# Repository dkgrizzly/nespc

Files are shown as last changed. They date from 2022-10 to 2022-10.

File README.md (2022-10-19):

# NES as an 8-Bit PC

This is very much a work in progress, and should be treated as such.

Based on the work done by [Joseph Marlin](https://github.com/jmarlin/) on his YouTube channel [TrackZero](https://www.youtube.com/c/TrackZeroFutzin).
Attaching a standard floppy disk controller (FDC) to a NES-001 game console with BASIC and Monitor in ROM.

I've separated the FDC to a mezzanine card which can be extended outside the case on a 40-pin IDC cable.
Partly due to the relative scarcity of the chips, and partly due to the complexity of the signal routing involved.
The FDC and additonal expansion cards share an 8-bit data and 8-bit address bus. The bus has eight select lines in addition to the FDC selects.

Expansion cards should be connected with 40-pin IDC edge connectors. The expansion bus cable should have three twists as show in expansion.txt.

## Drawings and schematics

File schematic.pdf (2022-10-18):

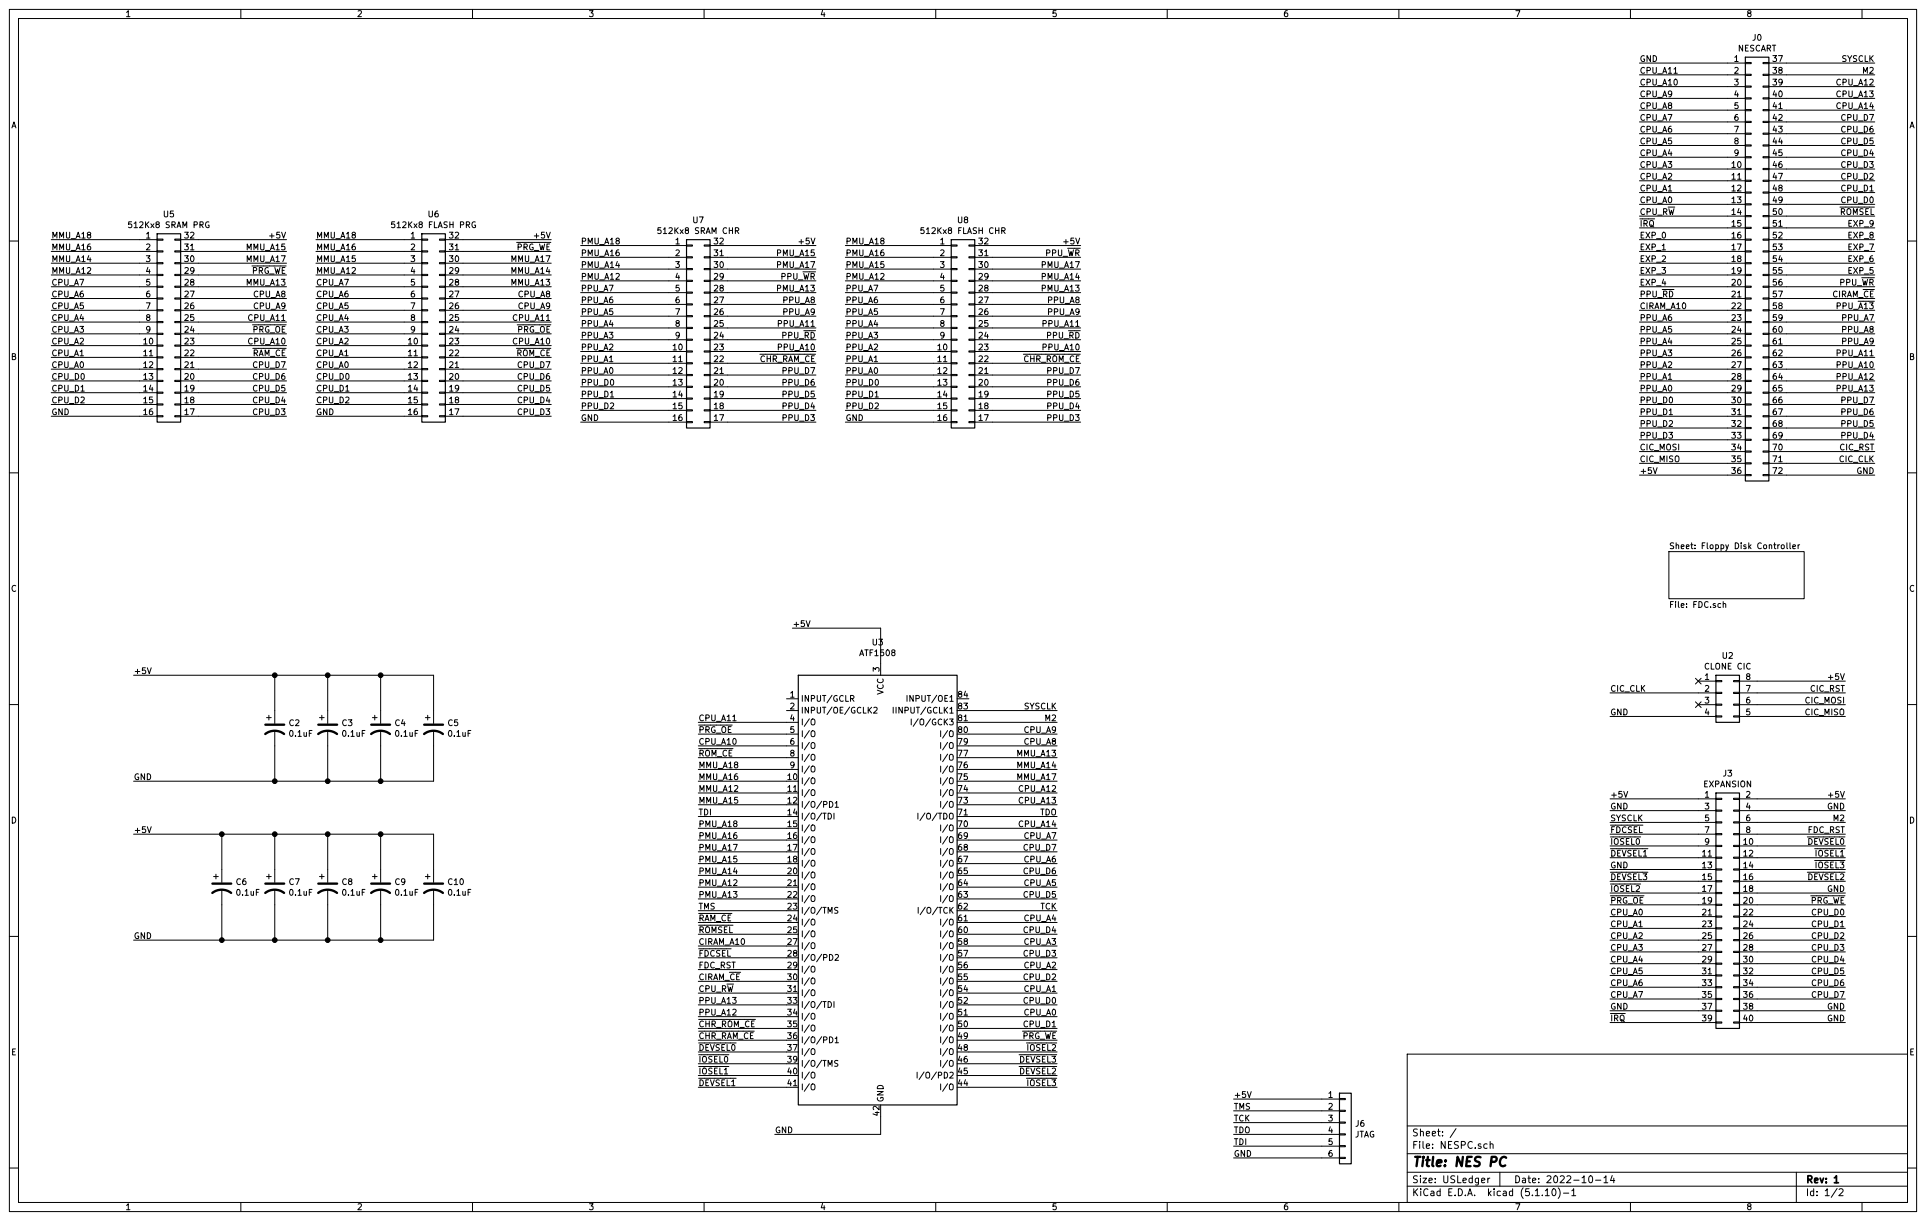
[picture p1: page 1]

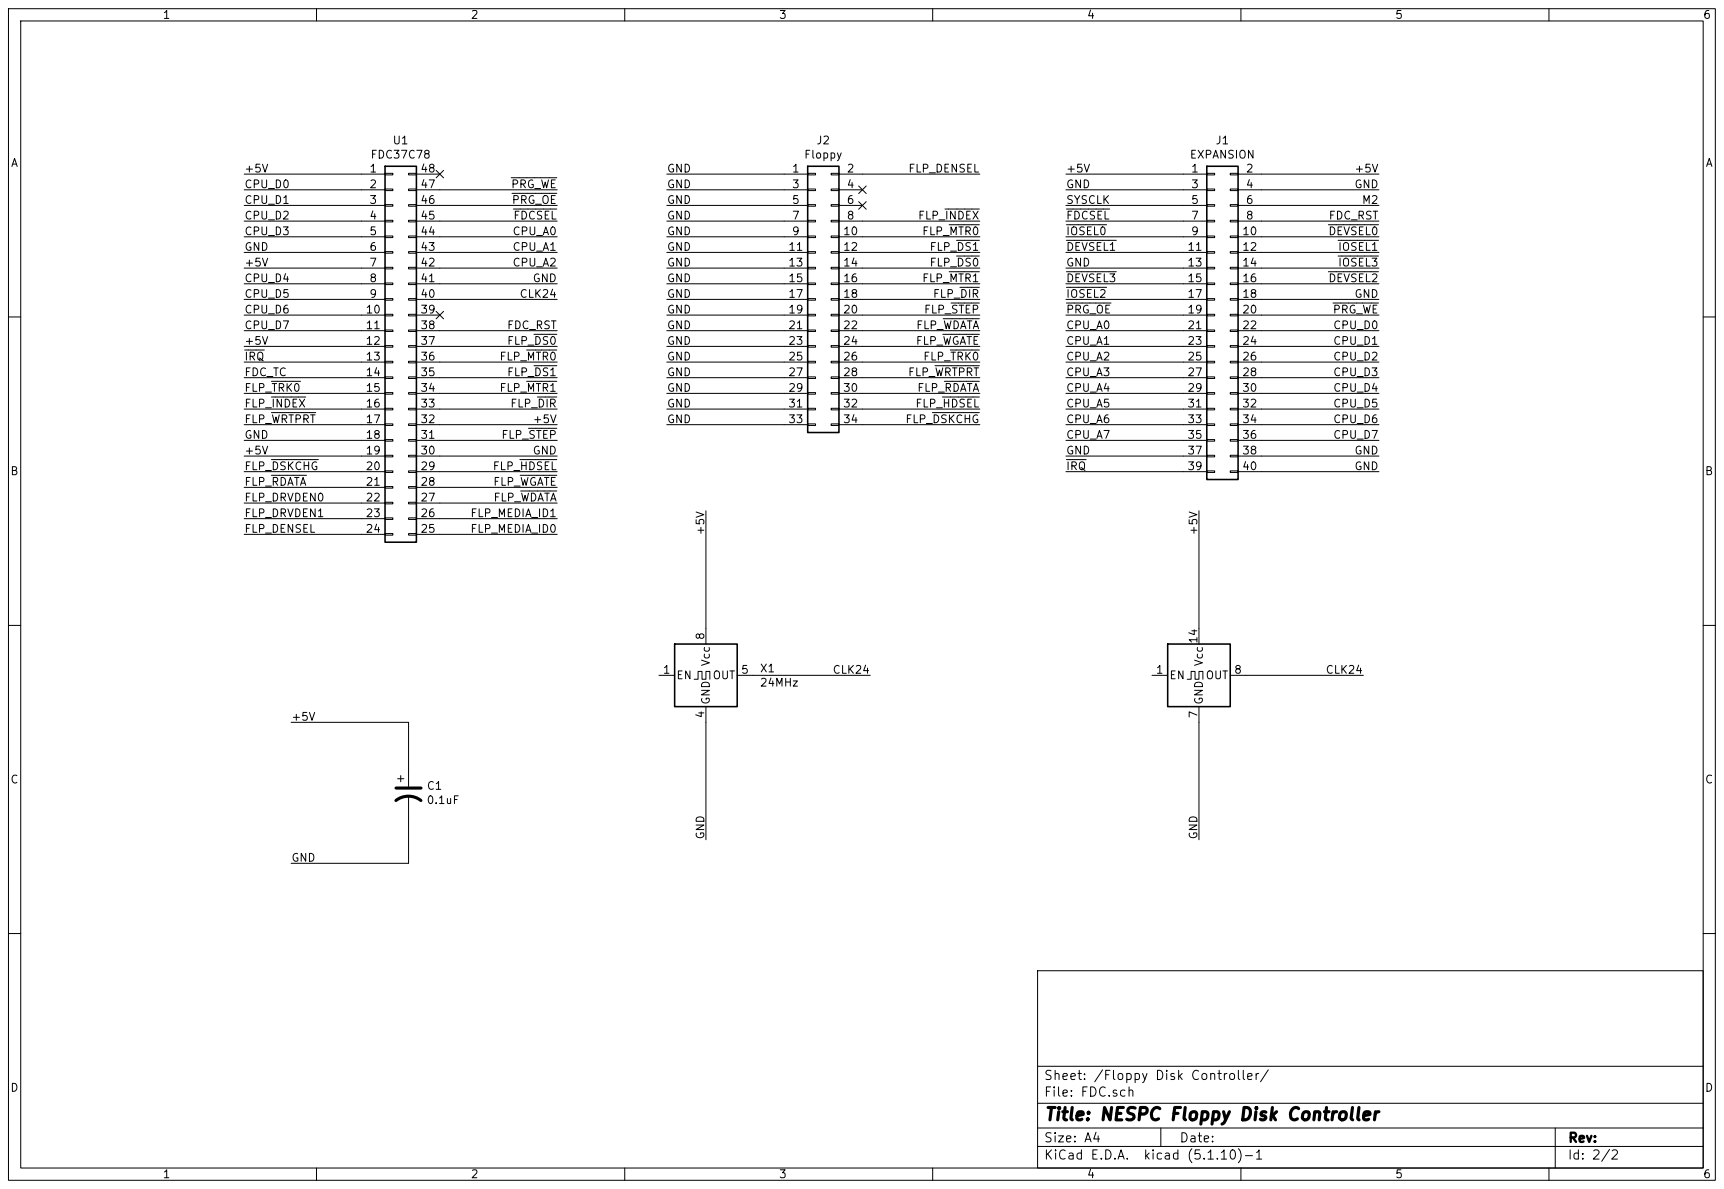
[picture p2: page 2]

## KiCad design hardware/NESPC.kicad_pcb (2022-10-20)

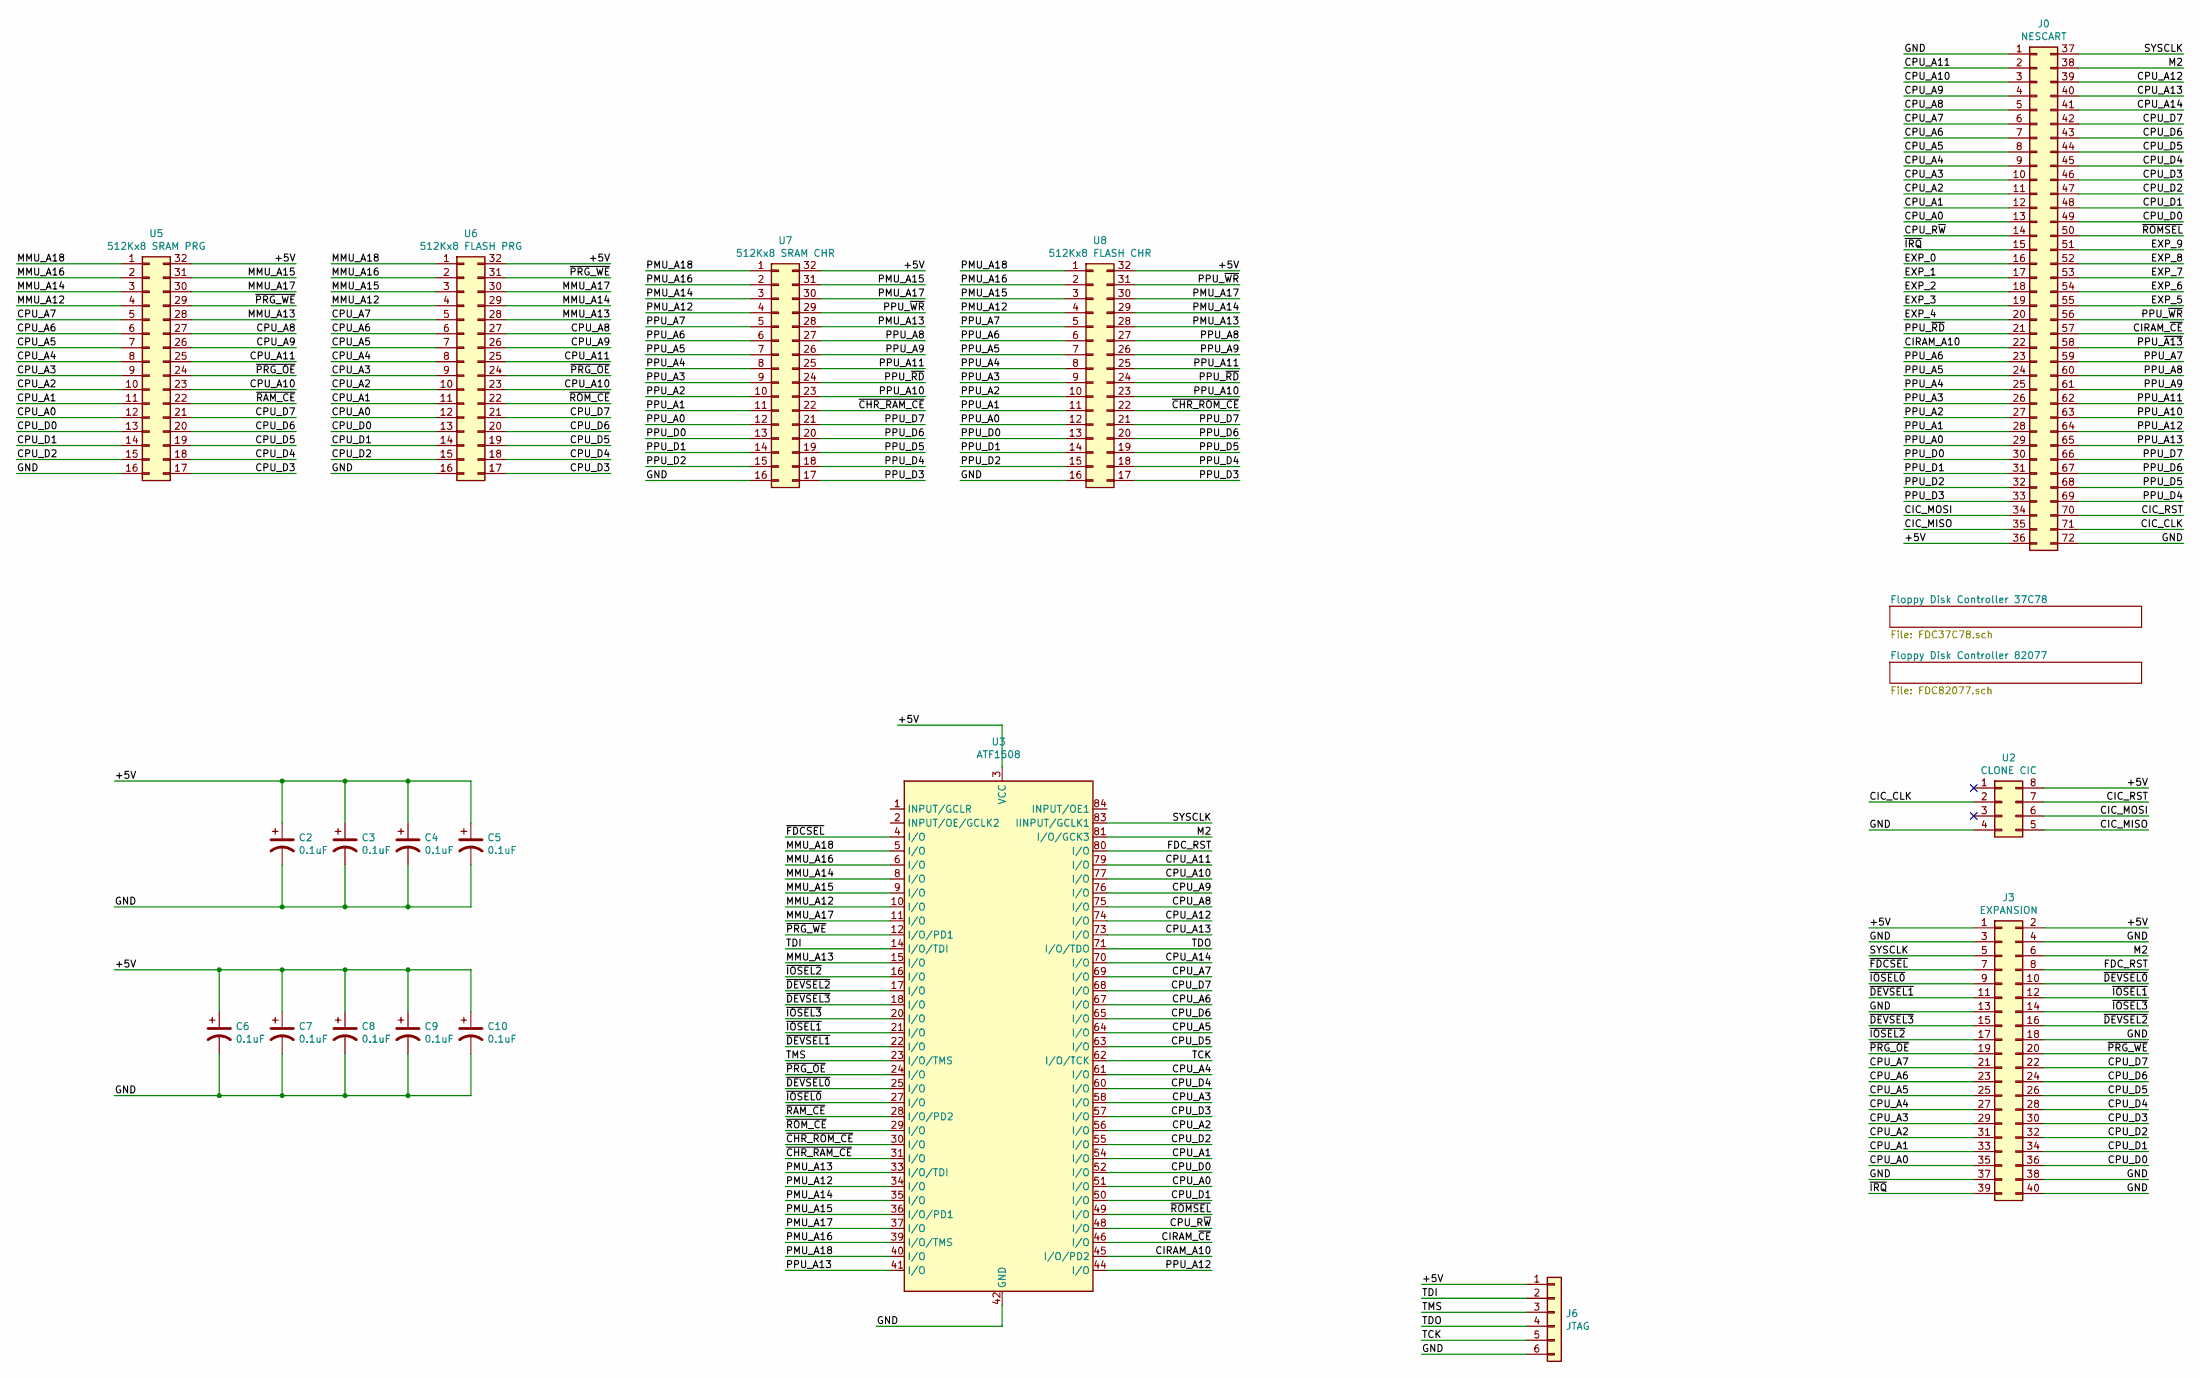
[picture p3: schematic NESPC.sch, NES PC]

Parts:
C2, C3, C4, C5, C6, C7, C8, C9, C10: 0.1uF; C_0603_1608Metric_Pad1.08x0.95mm_HandSolder
J0: NESCART; NES_CART
J3: EXPANSION; PinHeader_2x20_P2.54mm_Vertical
J6: JTAG; PinHeader_1x06_P2.54mm_Vertical
U2: CLONE CIC; DIP-8_W7.62mm
U3: ATF1508; PLCC-84
U5: 512Kx8 SRAM PRG; DIP-32_W15.24mm
U6: 512Kx8 FLASH PRG; DIP-32_W15.24mm
U7: 512Kx8 SRAM CHR; DIP-32_W15.24mm
U8: 512Kx8 FLASH CHR; DIP-32_W15.24mm

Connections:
/+5V: C2.1, C3.1, C4.1, C5.1, C6.1, C7.1, C8.1, C9.1, C10.1, J0.36, J3.1, J3.2, J6.1, U2.8, U3.3 (VCC), U3.13 (VCC), U3.26 (VCC), U3.38 (VCC), U3.43 (VCC), U3.53 (VCC), U3.66 (VCC), U3.78 (VCC), U5.32, U6.32, U7.32, U8.32
/CIC_CLK: J0.71, U2.2
/CIC_MISO: J0.35, U2.5
/CIC_MOSI: J0.34, U2.6
/CIC_RST: J0.70, U2.7
/CIRAM_A10: J0.22, U3.45 (I/O/PD2)
/CIRAM_~CE: J0.57, U3.46 (I/O)
/CPU_A0: J0.13, J3.35, U3.51 (I/O), U5.12, U6.12
/CPU_A1: J0.12, J3.33, U3.54 (I/O), U5.11, U6.11
/CPU_A2: J0.11, J3.31, U3.56 (I/O), U5.10, U6.10
/CPU_A3: J0.10, J3.29, U3.58 (I/O), U5.9, U6.9
/CPU_A4: J0.9, J3.27, U3.61 (I/O), U5.8, U6.8
/CPU_A5: J0.8, J3.25, U3.64 (I/O), U5.7, U6.7
/CPU_A6: J0.7, J3.23, U3.67 (I/O), U5.6, U6.6
/CPU_A7: J0.6, J3.21, U3.69 (I/O), U5.5, U6.5
/CPU_A8: J0.5, U3.75 (I/O), U5.27, U6.27
/CPU_A9: J0.4, U3.76 (I/O), U5.26, U6.26
/CPU_A10: J0.3, U3.77 (I/O), U5.23, U6.23
/CPU_A11: J0.2, U3.79 (I/O), U5.25, U6.25
/CPU_A12: J0.39, U3.74 (I/O)
/CPU_A13: J0.40, U3.73 (I/O)
/CPU_A14: J0.41, U3.70 (I/O)
/CPU_D0: J0.49, J3.36, U3.52 (I/O), U5.13, U6.13
/CPU_D1: J0.48, J3.34, U3.50 (I/O), U5.14, U6.14
/CPU_D2: J0.47, J3.32, U3.55 (I/O), U5.15, U6.15
/CPU_D3: J0.46, J3.30, U3.57 (I/O), U5.17, U6.17
/CPU_D4: J0.45, J3.28, U3.60 (I/O), U5.18, U6.18
/CPU_D5: J0.44, J3.26, U3.63 (I/O), U5.19, U6.19
/CPU_D6: J0.43, J3.24, U3.65 (I/O), U5.20, U6.20
/CPU_D7: J0.42, J3.22, U3.68 (I/O), U5.21, U6.21
/CPU_R~W: J0.14, U3.48 (I/O)
/EXP_0: J0.16
/EXP_1: J0.17
/EXP_2: J0.18
/EXP_3: J0.19
/EXP_4: J0.20
/EXP_5: J0.55
/EXP_6: J0.54
/EXP_7: J0.53
/EXP_8: J0.52
/EXP_9: J0.51
/FDC_RST: J3.8, U3.80 (I/O)
/GND: C2.2, C3.2, C4.2, C5.2, C6.2, C7.2, C8.2, C9.2, C10.2, J0.1, J0.72, J3.3, J3.4, J3.13, J3.18, J3.37, J3.38, J3.40, J6.6, U2.4, U3.7 (GND), U3.19 (GND), U3.32 (GND), U3.42 (GND), U3.47 (GND), U3.59 (GND), U3.72 (GND), U3.82 (GND), U5.16, U6.16, U7.16, U8.16
/M2: J0.38, J3.6, U3.81 (I/O/GCK3)
/MMU_A12: U3.10 (I/O), U5.4, U6.4
/MMU_A13: U3.15 (I/O), U5.28, U6.28
/MMU_A14: U3.8 (I/O), U5.3, U6.29
/MMU_A15: U3.9 (I/O), U5.31, U6.3
/MMU_A16: U3.6 (I/O), U5.2, U6.2
/MMU_A17: U3.11 (I/O), U5.30, U6.30
/MMU_A18: U3.5 (I/O), U5.1, U6.1
/PMU_A12: U3.34 (I/O), U7.4, U8.4
/PMU_A13: U3.33 (I/O/TDI), U7.28, U8.28
/PMU_A14: U3.35 (I/O), U7.3, U8.29
/PMU_A15: U3.36 (I/O/PD1), U7.31, U8.3
/PMU_A16: U3.39 (I/O/TMS), U7.2, U8.2
/PMU_A17: U3.37 (I/O), U7.30, U8.30
/PMU_A18: U3.40 (I/O), U7.1, U8.1
/PPU_A0: J0.29, U7.12, U8.12
/PPU_A1: J0.28, U7.11, U8.11
/PPU_A2: J0.27, U7.10, U8.10
/PPU_A3: J0.26, U7.9, U8.9
/PPU_A4: J0.25, U7.8, U8.8
/PPU_A5: J0.24, U7.7, U8.7
/PPU_A6: J0.23, U7.6, U8.6
/PPU_A7: J0.59, U7.5, U8.5
/PPU_A8: J0.60, U7.27, U8.27
/PPU_A9: J0.61, U7.26, U8.26
/PPU_A10: J0.63, U7.23, U8.23
/PPU_A11: J0.62, U7.25, U8.25
/PPU_A12: J0.64, U3.44 (I/O)
/PPU_A13: J0.65, U3.41 (I/O)
/PPU_D0: J0.30, U7.13, U8.13
/PPU_D1: J0.31, U7.14, U8.14
/PPU_D2: J0.32, U7.15, U8.15
/PPU_D3: J0.33, U7.17, U8.17
/PPU_D4: J0.69, U7.18, U8.18
/PPU_D5: J0.68, U7.19, U8.19
/PPU_D6: J0.67, U7.20, U8.20
/PPU_D7: J0.66, U7.21, U8.21
/PPU_~A13: J0.58
/PPU_~RD: J0.21, U7.24, U8.24
/PPU_~WR: J0.56, U7.29, U8.31
/SYSCLK: J0.37, J3.5, U3.83 (IINPUT/GCLK1)
/TCK: J6.5, U3.62 (I/O/TCK)
/TDI: J6.2, U3.14 (I/O/TDI)
/TDO: J6.4, U3.71 (I/O/TDO)
/TMS: J6.3, U3.23 (I/O/TMS)
/~CHR_RAM_CE: U3.31 (I/O), U7.22
/~CHR_ROM_CE: U3.30 (I/O), U8.22
/~DEVSEL0: J3.10, U3.25 (I/O)
/~DEVSEL1: J3.11, U3.22 (I/O)
/~DEVSEL2: J3.16, U3.17 (I/O)
/~DEVSEL3: J3.15, U3.18 (I/O)
/~FDCSEL: J3.7, U3.4 (I/O)
/~IOSEL0: J3.9, U3.27 (I/O)
/~IOSEL1: J3.12, U3.21 (I/O)
/~IOSEL2: J3.17, U3.16 (I/O)
/~IOSEL3: J3.14, U3.20 (I/O)
/~IRQ: J0.15, J3.39
/~PRG_OE: J3.19, U3.24 (I/O), U5.24, U6.24
/~PRG_WE: J3.20, U3.12 (I/O/PD1), U5.29, U6.31
/~RAM_CE: U3.28 (I/O/PD2), U5.22
/~ROMSEL: J0.50, U3.49 (I/O)
/~ROM_CE: U3.29 (I/O), U6.22

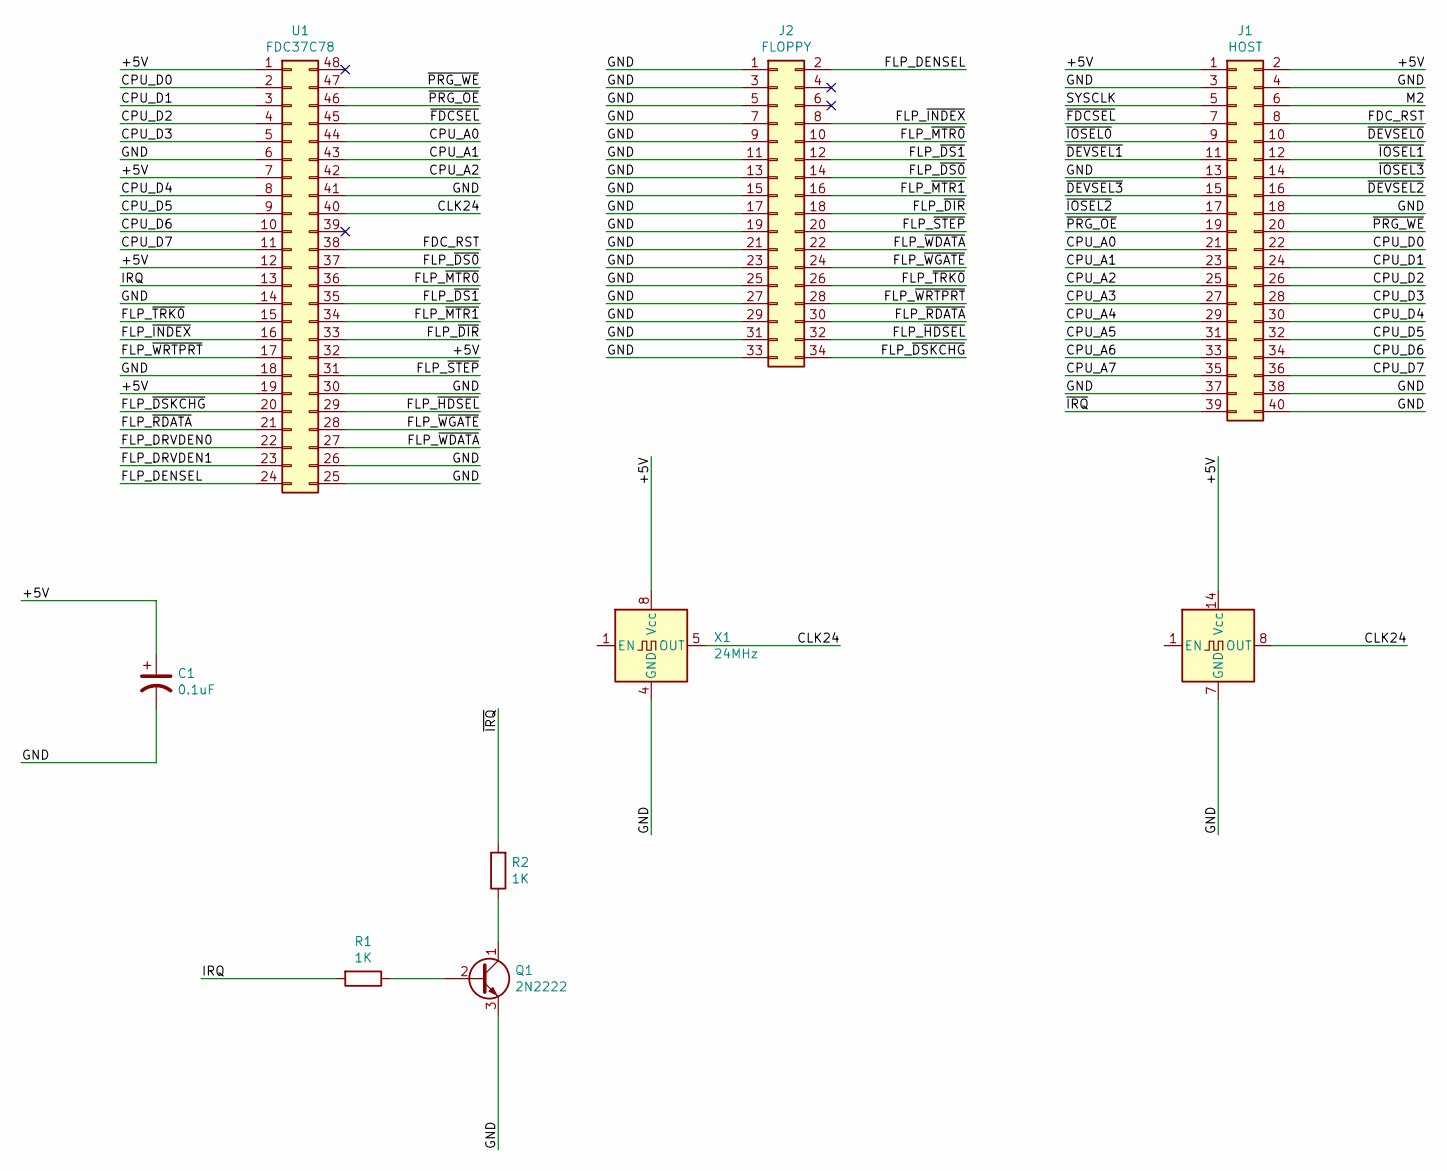
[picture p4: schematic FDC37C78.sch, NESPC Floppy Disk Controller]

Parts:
C1: 0.1uF; C_0603_1608Metric_Pad1.08x0.95mm_HandSolder
J1: HOST; PinHeader_2x20_P2.54mm_Vertical
J2: FLOPPY; PinHeader_2x17_P2.54mm_Vertical
Q1: 2N2222; TO-92S_Wide
R1, R2: 1K; R_0603_1608Metric_Pad0.98x0.95mm_HandSolder
U1: FDC37C78; LQFP-48_7x7mm_P0.5mm
X1: 24MHz; Oscillator_DIP-8
X2: CXO_DIP14; Oscillator_DIP-14

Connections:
/Floppy Disk Controller 37C78/+5V: C1.1, J1.1, J1.2, U1.1, U1.7, U1.12, U1.19, U1.32, X1.8 (Vcc), X2.14 (Vcc)
/Floppy Disk Controller 37C78/CLK24: U1.40, X1.5 (OUT), X2.8 (OUT)
/Floppy Disk Controller 37C78/CPU_A0: J1.21, U1.44
/Floppy Disk Controller 37C78/CPU_A1: J1.23, U1.43
/Floppy Disk Controller 37C78/CPU_A2: J1.25, U1.42
/Floppy Disk Controller 37C78/CPU_A3: J1.27
/Floppy Disk Controller 37C78/CPU_A4: J1.29
/Floppy Disk Controller 37C78/CPU_A5: J1.31
/Floppy Disk Controller 37C78/CPU_A6: J1.33
/Floppy Disk Controller 37C78/CPU_A7: J1.35
/Floppy Disk Controller 37C78/CPU_D0: J1.22, U1.2
/Floppy Disk Controller 37C78/CPU_D1: J1.24, U1.3
/Floppy Disk Controller 37C78/CPU_D2: J1.26, U1.4
/Floppy Disk Controller 37C78/CPU_D3: J1.28, U1.5
/Floppy Disk Controller 37C78/CPU_D4: J1.30, U1.8
/Floppy Disk Controller 37C78/CPU_D5: J1.32, U1.9
/Floppy Disk Controller 37C78/CPU_D6: J1.34, U1.10
/Floppy Disk Controller 37C78/CPU_D7: J1.36, U1.11
/Floppy Disk Controller 37C78/FDC_RST: J1.8, U1.38
/Floppy Disk Controller 37C78/FLP_DENSEL: J2.2, U1.24
/Floppy Disk Controller 37C78/FLP_DRVDEN0: U1.22
/Floppy Disk Controller 37C78/FLP_DRVDEN1: U1.23
/Floppy Disk Controller 37C78/FLP_~DIR: J2.18, U1.33
/Floppy Disk Controller 37C78/FLP_~DS0: J2.14, U1.37
/Floppy Disk Controller 37C78/FLP_~DS1: J2.12, U1.35
/Floppy Disk Controller 37C78/FLP_~DSKCHG: J2.34, U1.20
/Floppy Disk Controller 37C78/FLP_~HDSEL: J2.32, U1.29
/Floppy Disk Controller 37C78/FLP_~INDEX: J2.8, U1.16
/Floppy Disk Controller 37C78/FLP_~MTR0: J2.10, U1.36
/Floppy Disk Controller 37C78/FLP_~MTR1: J2.16, U1.34
/Floppy Disk Controller 37C78/FLP_~RDATA: J2.30, U1.21
/Floppy Disk Controller 37C78/FLP_~STEP: J2.20, U1.31
/Floppy Disk Controller 37C78/FLP_~TRK0: J2.26, U1.15
/Floppy Disk Controller 37C78/FLP_~WDATA: J2.22, U1.27
/Floppy Disk Controller 37C78/FLP_~WGATE: J2.24, U1.28
/Floppy Disk Controller 37C78/FLP_~WRTPRT: J2.28, U1.17
/Floppy Disk Controller 37C78/GND: C1.2, J1.3, J1.4, J1.13, J1.18, J1.37, J1.38, J1.40, J2.1, J2.3, J2.5, J2.7, J2.9, J2.11, J2.13, J2.15, J2.17, J2.19, J2.21, J2.23, J2.25, J2.27, J2.29, J2.31, J2.33, Q1.3 (E), U1.6, U1.14, U1.18, U1.25, U1.26, U1.30, U1.41, X1.4 (GND), X2.7 (GND)
/Floppy Disk Controller 37C78/IRQ: R1.2, U1.13
/Floppy Disk Controller 37C78/M2: J1.6
/Floppy Disk Controller 37C78/SYSCLK: J1.5
/Floppy Disk Controller 37C78/~DEVSEL0: J1.10
/Floppy Disk Controller 37C78/~DEVSEL1: J1.11
/Floppy Disk Controller 37C78/~DEVSEL2: J1.16
/Floppy Disk Controller 37C78/~DEVSEL3: J1.15
/Floppy Disk Controller 37C78/~FDCSEL: J1.7, U1.45
/Floppy Disk Controller 37C78/~IOSEL0: J1.9
/Floppy Disk Controller 37C78/~IOSEL1: J1.12
/Floppy Disk Controller 37C78/~IOSEL2: J1.17
/Floppy Disk Controller 37C78/~IOSEL3: J1.14
/Floppy Disk Controller 37C78/~IRQ: J1.39, R2.2
/Floppy Disk Controller 37C78/~PRG_OE: J1.19, U1.46
/Floppy Disk Controller 37C78/~PRG_WE: J1.20, U1.47
unnamed: Q1.1 (C), R2.1
unnamed: Q1.2 (B), R1.1

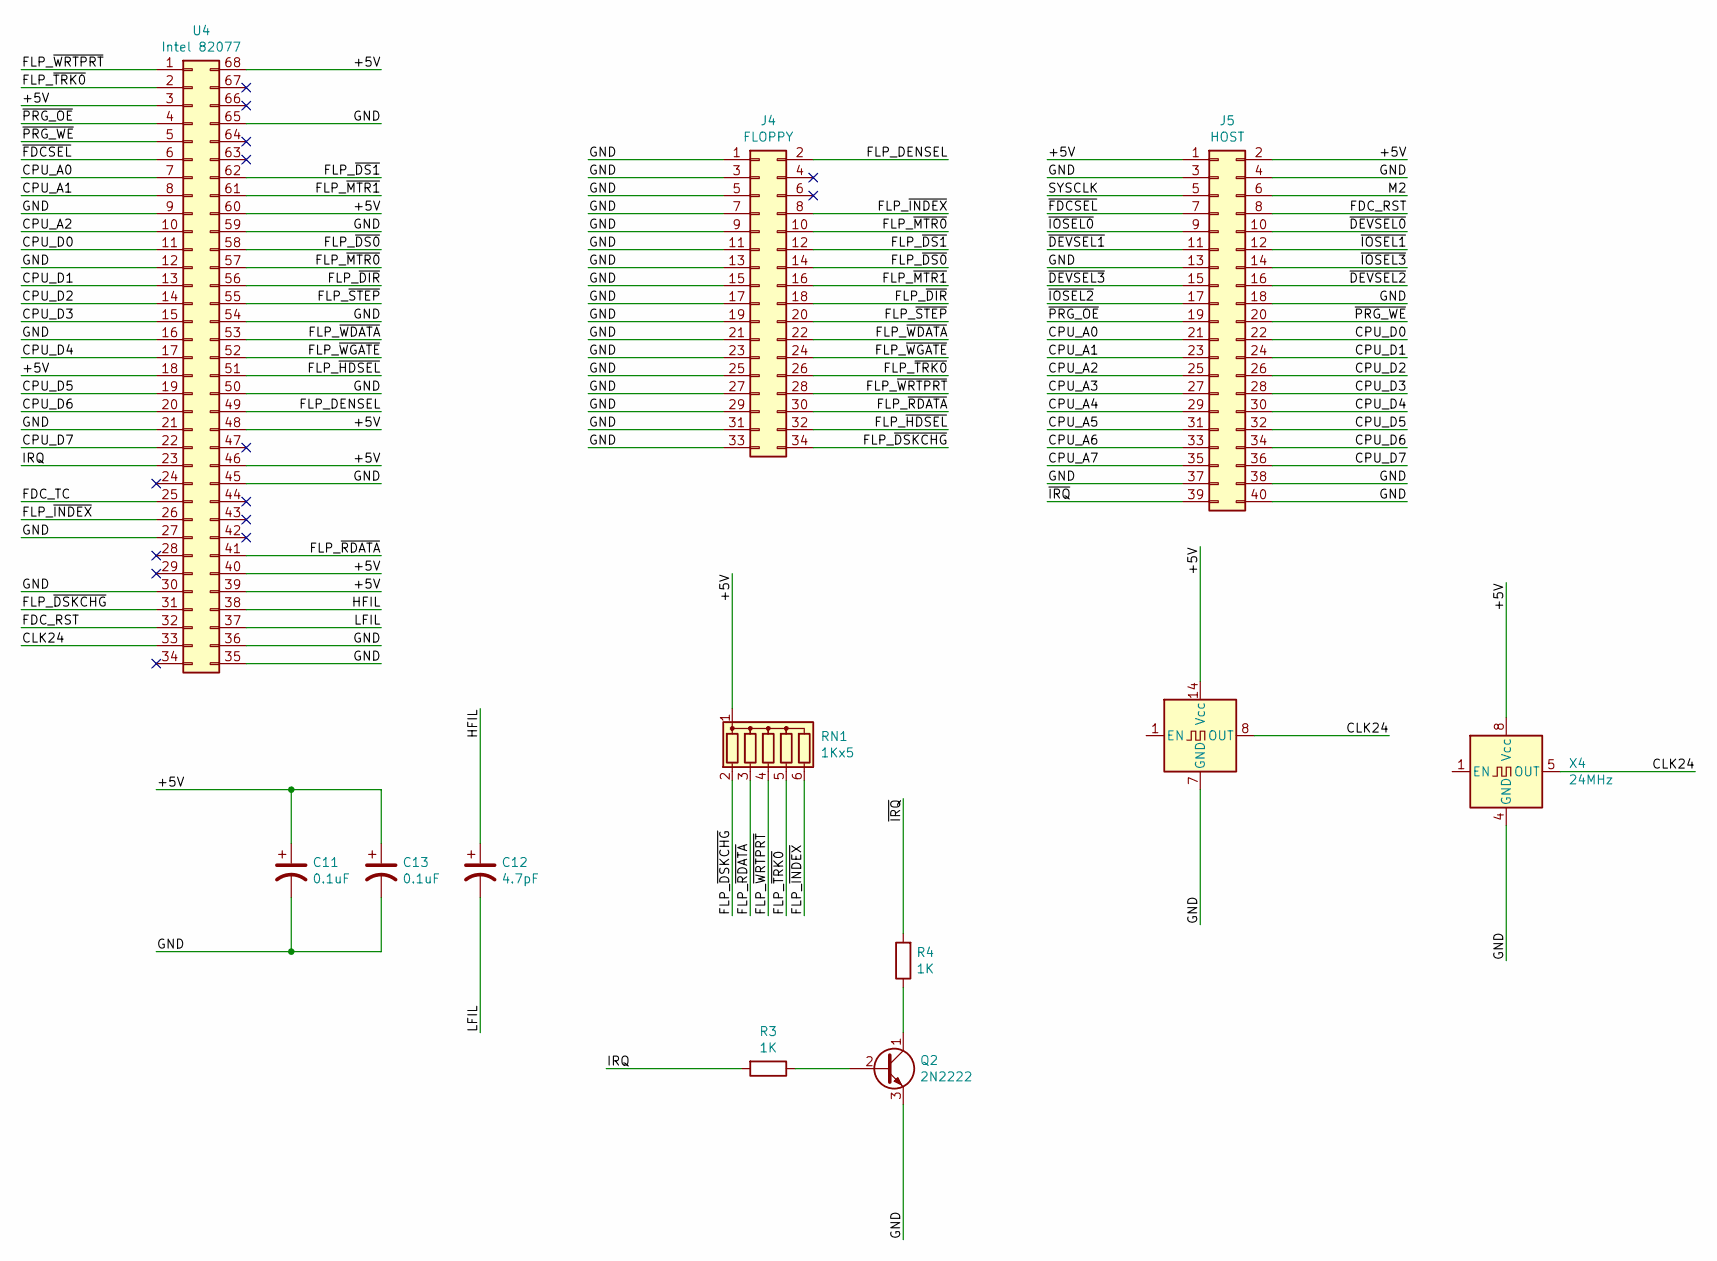
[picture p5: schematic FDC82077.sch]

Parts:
C11, C13: 0.1uF; C_0603_1608Metric_Pad1.08x0.95mm_HandSolder
C12: 4.7pF; C_0603_1608Metric_Pad1.08x0.95mm_HandSolder
J4: FLOPPY; PinHeader_2x17_P2.54mm_Vertical
J5: HOST; PinHeader_2x20_P2.54mm_Vertical
Q2: 2N2222; TO-92S_Wide
R3, R4: 1K; R_0603_1608Metric_Pad0.98x0.95mm_HandSolder
RN1: 1Kx5; R_Array_SIP6
U4: Intel 82077; PLCC-68
X3: CXO_DIP14; Oscillator_DIP-14
X4: 24MHz; Oscillator_DIP-8

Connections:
/Floppy Disk Controller 82077/+5V: C11.1, C13.1, J5.1, J5.2, RN1.1 (common), U4.3, U4.18, U4.39, U4.40, U4.46, U4.48, U4.60, U4.68, X3.14 (Vcc), X4.8 (Vcc)
/Floppy Disk Controller 82077/CLK24: U4.33, X3.8 (OUT), X4.5 (OUT)
/Floppy Disk Controller 82077/CPU_A0: J5.21, U4.7
/Floppy Disk Controller 82077/CPU_A1: J5.23, U4.8
/Floppy Disk Controller 82077/CPU_A2: J5.25, U4.10
/Floppy Disk Controller 82077/CPU_A3: J5.27
/Floppy Disk Controller 82077/CPU_A4: J5.29
/Floppy Disk Controller 82077/CPU_A5: J5.31
/Floppy Disk Controller 82077/CPU_A6: J5.33
/Floppy Disk Controller 82077/CPU_A7: J5.35
/Floppy Disk Controller 82077/CPU_D0: J5.22, U4.11
/Floppy Disk Controller 82077/CPU_D1: J5.24, U4.13
/Floppy Disk Controller 82077/CPU_D2: J5.26, U4.14
/Floppy Disk Controller 82077/CPU_D3: J5.28, U4.15
/Floppy Disk Controller 82077/CPU_D4: J5.30, U4.17
/Floppy Disk Controller 82077/CPU_D5: J5.32, U4.19
/Floppy Disk Controller 82077/CPU_D6: J5.34, U4.20
/Floppy Disk Controller 82077/CPU_D7: J5.36, U4.22
/Floppy Disk Controller 82077/FDC_RST: J5.8, U4.32
/Floppy Disk Controller 82077/FDC_TC: U4.25
/Floppy Disk Controller 82077/FLP_DENSEL: J4.2, U4.49
/Floppy Disk Controller 82077/FLP_~DIR: J4.18, U4.56
/Floppy Disk Controller 82077/FLP_~DS0: J4.14, U4.58
/Floppy Disk Controller 82077/FLP_~DS1: J4.12, U4.62
/Floppy Disk Controller 82077/FLP_~DSKCHG: J4.34, RN1.2 (R1), U4.31
/Floppy Disk Controller 82077/FLP_~HDSEL: J4.32, U4.51
/Floppy Disk Controller 82077/FLP_~INDEX: J4.8, RN1.6 (R5), U4.26
/Floppy Disk Controller 82077/FLP_~MTR0: J4.10, U4.57
/Floppy Disk Controller 82077/FLP_~MTR1: J4.16, U4.61
/Floppy Disk Controller 82077/FLP_~RDATA: J4.30, RN1.3 (R2), U4.41
/Floppy Disk Controller 82077/FLP_~STEP: J4.20, U4.55
/Floppy Disk Controller 82077/FLP_~TRK0: J4.26, RN1.5 (R4), U4.2
/Floppy Disk Controller 82077/FLP_~WDATA: J4.22, U4.53
/Floppy Disk Controller 82077/FLP_~WGATE: J4.24, U4.52
/Floppy Disk Controller 82077/FLP_~WRTPRT: J4.28, RN1.4 (R3), U4.1
/Floppy Disk Controller 82077/GND: C11.2, C13.2, J4.1, J4.3, J4.5, J4.7, J4.9, J4.11, J4.13, J4.15, J4.17, J4.19, J4.21, J4.23, J4.25, J4.27, J4.29, J4.31, J4.33, J5.3, J5.4, J5.13, J5.18, J5.37, J5.38, J5.40, Q2.3 (E), U4.9, U4.12, U4.16, U4.21, U4.27, U4.30, U4.35, U4.36, U4.45, U4.50, U4.54, U4.59, U4.65, X3.7 (GND), X4.4 (GND)
/Floppy Disk Controller 82077/HFIL: C12.1, U4.38
/Floppy Disk Controller 82077/IRQ: R3.2, U4.23
/Floppy Disk Controller 82077/LFIL: C12.2, U4.37
/Floppy Disk Controller 82077/M2: J5.6
/Floppy Disk Controller 82077/SYSCLK: J5.5
/Floppy Disk Controller 82077/~DEVSEL0: J5.10
/Floppy Disk Controller 82077/~DEVSEL1: J5.11
/Floppy Disk Controller 82077/~DEVSEL2: J5.16
/Floppy Disk Controller 82077/~DEVSEL3: J5.15
/Floppy Disk Controller 82077/~FDCSEL: J5.7, U4.6
/Floppy Disk Controller 82077/~IOSEL0: J5.9
/Floppy Disk Controller 82077/~IOSEL1: J5.12
/Floppy Disk Controller 82077/~IOSEL2: J5.17
/Floppy Disk Controller 82077/~IOSEL3: J5.14
/Floppy Disk Controller 82077/~IRQ: J5.39, R4.2
/Floppy Disk Controller 82077/~PRG_OE: J5.19, U4.4
/Floppy Disk Controller 82077/~PRG_WE: J5.20, U4.5
unnamed: Q2.1 (C), R4.1
unnamed: Q2.2 (B), R3.1

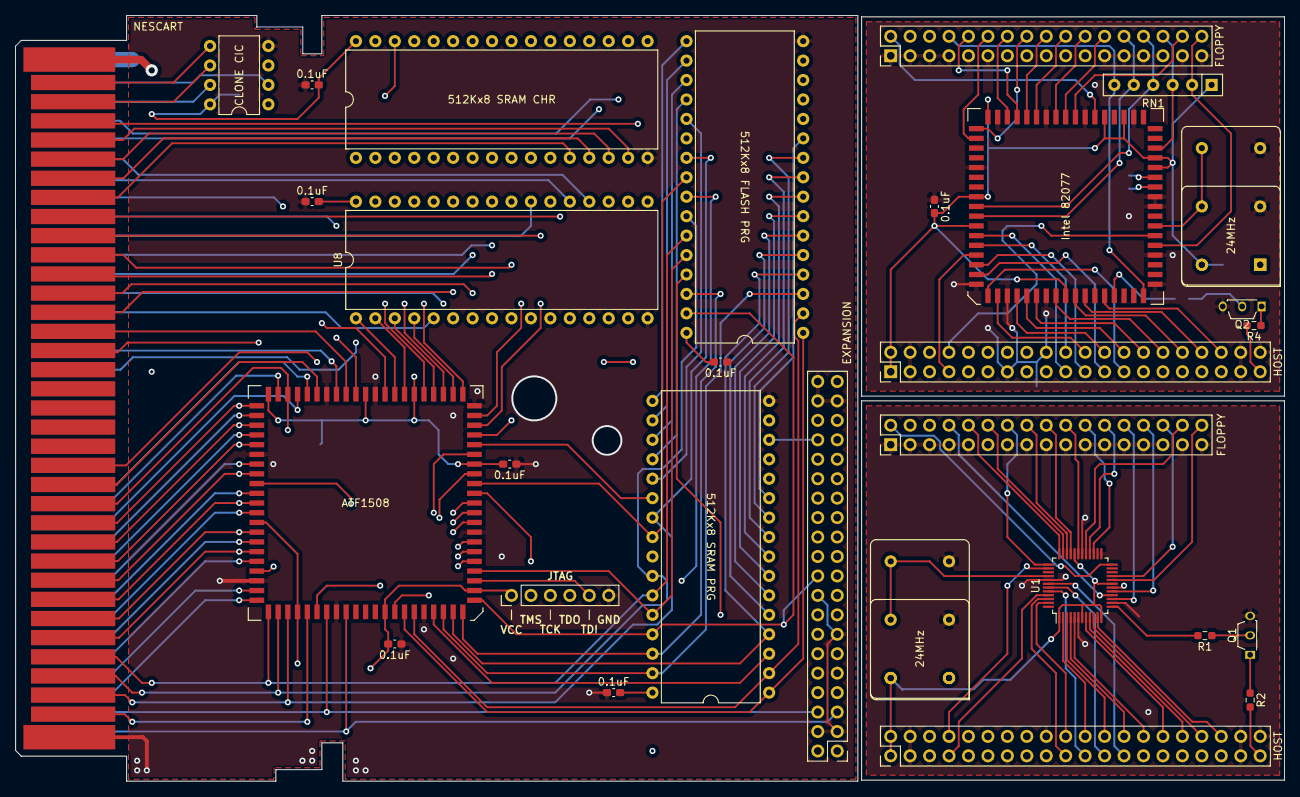
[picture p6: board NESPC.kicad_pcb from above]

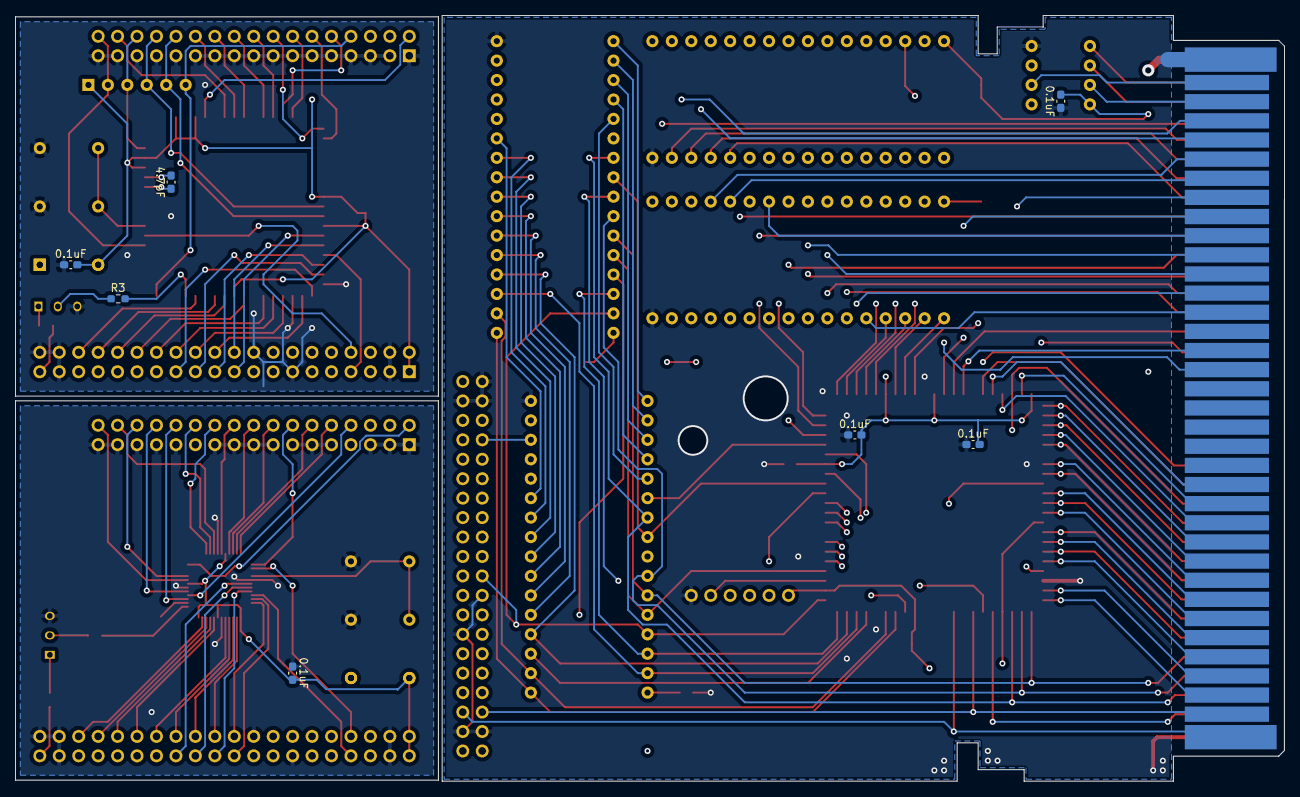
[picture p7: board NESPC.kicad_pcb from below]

Board: 4 copper layers, 165.7 x 100.0 mm, 39 parts (7 on the bottom side), 170 nets.

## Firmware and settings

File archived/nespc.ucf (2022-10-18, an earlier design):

#PINLOCK_BEGIN

#Sun Oct 16 22:00:04 2022

NET "CPU_A<0>"       LOC =  "S:PIN13";
NET "CPU_A<1>"       LOC =  "S:PIN62";
NET "CPU_A<2>"       LOC =  "S:PIN1";
NET "CPU_A<3>"       LOC =  "S:PIN63";
NET "CPU_A<4>"       LOC =  "S:PIN64";
NET "CPU_A<5>"       LOC =  "S:PIN6";
NET "CPU_A<6>"       LOC =  "S:PIN17";
NET "CPU_D<0>"       LOC =  "S:PIN4";
NET "CPU_D<1>"       LOC =  "S:PIN59";
NET "CPU_D<2>"       LOC =  "S:PIN2";
NET "CPU_D<3>"       LOC =  "S:PIN5";
NET "CPU_D<4>"       LOC =  "S:PIN61";
NET "CPU_D<5>"       LOC =  "S:PIN7";
NET "CPU_D<6>"       LOC =  "S:PIN16";
NET "CPU_D<7>"       LOC =  "S:PIN33";
NET "CPU_RW"         LOC =  "S:PIN58";
NET "M2"             LOC =  "S:PIN36";
NET "PPU_A12"        LOC =  "S:PIN27";
NET "PPU_A13"        LOC =  "S:PIN60";
NET "nROMSEL"        LOC =  "S:PIN20";
NET "SYSCLK"         LOC =  "S:PIN15";
NET "CHR_ROM_nCE"    LOC =  "S:PIN43";
NET "CHR_RAM_nCE"    LOC =  "S:PIN46";
NET "CI_RAM_nCE"     LOC =  "S:PIN24";
NET "CPU_nRD"        LOC =  "S:PIN56";
NET "CPU_nWR"        LOC =  "S:PIN57";
NET "FDC_nCE"        LOC =  "S:PIN22";
NET "FDC_nRST"       LOC =  "S:PIN31";
NET "MMU_A<0>"       LOC =  "S:PIN18";
NET "MMU_A<1>"       LOC =  "S:PIN11";
NET "MMU_A<2>"       LOC =  "S:PIN10";
NET "MMU_A<3>"       LOC =  "S:PIN9";
NET "MMU_A<4>"       LOC =  "S:PIN12";
NET "MMU_A<5>"       LOC =  "S:PIN8";
NET "MMU_A<6>"       LOC =  "S:PIN19";
NET "PMU_A<0>"       LOC =  "S:PIN47";
NET "PMU_A<1>"       LOC =  "S:PIN44";
NET "PMU_A<2>"       LOC =  "S:PIN49";
NET "PMU_A<3>"       LOC =  "S:PIN45";
NET "PMU_A<4>"       LOC =  "S:PIN51";
NET "PMU_A<5>"       LOC =  "S:PIN48";
NET "PMU_A<6>"       LOC =  "S:PIN23";
NET "PRG_RAM_nCE"    LOC =  "S:PIN52";
NET "PRG_ROM_nCE"    LOC =  "S:PIN50";
NET "SEL<0>"         LOC =  "S:PIN34";
NET "SEL<1>"         LOC =  "S:PIN25";
NET "SEL<2>"         LOC =  "S:PIN39";
NET "SEL<3>"         LOC =  "S:PIN40";
NET "SEL<4>"         LOC =  "S:PIN35";
NET "SEL<5>"         LOC =  "S:PIN42";
NET "SEL<6>"         LOC =  "S:PIN38";
NET "SEL<7>"         LOC =  "S:PIN32";
#PINLOCK_END

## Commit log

2022-10-14 CUPL Compliance
    [NESPC.sch]
2022-10-18 PCB for ATF1508 Based Cart
    [FDC.sch, NESPC.kicad_pcb, NESPC.sch]
2022-10-18 FDC wiring
    [FDC.sch, NESPC.kicad_pcb, NESPC.sch]
2022-10-18 Schematic PDF
2022-10-19 Intel 82077 FDC and more rework
    [FDC37C78.sch, FDC82077.sch, NESPC-Cart.kicad_pcb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]
2022-10-19 Pin remapping final final final really this time
    [NESPC-Cart.kicad_pcb, NESPC.sch]
2022-10-20 Finalized boards sent out for Rev.0
    [FDC37C78.sch, FDC82077.sch, NESPC-Cart.kicad_pcb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]
